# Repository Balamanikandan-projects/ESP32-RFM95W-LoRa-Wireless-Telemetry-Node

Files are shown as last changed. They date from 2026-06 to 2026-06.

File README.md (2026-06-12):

# Custom ESP32 & RFM95W LoRa Wireless Telemetry Node

[Full 3D board render]



A compact, high-performance, **4-layer custom PCB design** integrating an ESP32-WROOM-32E microcontroller with an RFM95W sub-GHz LoRa radio module. This hardware platform is engineered as a robust, low-power remote data acquisition node featuring an optimized power distribution network (PDN) and controlled-impedance RF path layout.

---

## 🚀 Key Features & Architectural Highlights

* **Core Processing:** Powered by an **ESP32-WROOM-32E**, managing application firmware, peripheral communication via SPI/UART, and deep-sleep low-power states.
* **Long-Range RF Connectivity:** Integrated **HOPERF RFM95W LoRa module** mapped over a high-speed synchronous SPI bus for long-range, sub-GHz wireless telemetry.
* **Advanced 4-Layer Stackup:** Engineered with a strict high-speed layout methodology:
  * **Layer 1 (Top):** Signal routing, RF traces, and critical high-frequency component placement.
  * **Layer 2 (Inner 1):** Solid **GND Plane** for low-impedance return paths and EMI shielding.
  * **Layer 3 (Inner 2):** Split **Power Plane** (+3.3V, VBAT, +5V) to ensure low-drop DC distribution.
  * **Layer 4 (Bottom):** Slow-moving control signals, programming buses, and local ground copper fill.
* **Dual-Input Automated Power Path:** Seamless automated power switching between USB Type-C ($5\text{V}$) and a Lithium-Polymer battery ($3.7\text{V} - 4.2\text{V}$) using a low-forward-drop Schottky barrier isolation diode.
* **Integrated Battery Management:** Onboard **TP4056 linear LiPo battery charger** with a programmable constant-current resistor network to regulate charging states safely.
* **High-Transient Power Regulation:** Equipped with a **TLV62569 synchronous buck regulator** providing a rock-solid $+3.3\text{V}$ rail capable of delivering up to $2\text{A}$ to handle active RF and Wi-Fi transmission bursts without voltage sags.

![PCB Layer Stackup Configuration]




---

## 🛠️ Hardware System Architecture & Floorplanning

The physical PCB layout is meticulously split into isolated functional blocks (Islands) to maximize signal integrity and prevent noise coupling:

### 1. Power Input & Charging (Zone 1)
* **USB-C Interface:** Standard 16-pin USB-C receptacle configured with dedicated $5.1\text{k}\Omega$ pull-down resistors on CC1/CC2 lines for downstream power negotiation.
* **Input Filtering:** High-frequency ceramic decoupling capacitors ($10\mu\text{F}$, 0603) placed immediately adjacent to the VBUS pins to suppress transient input ripples.

### 2. DC-DC High-Frequency Switching Regulator (Zone 2)
* **Switching Loop Minimization:** The $2.2\mu\text{H}$ power inductor ($L_1$) and input/output filters are placed directly next to the TLV62569 pads to minimize the high $di/dt$ switching loop area.
* **Isolated Feedback Network:** The voltage divider feedback resistors ($R_4, R_5$) are trace-isolated away from the noisy switching node to prevent output voltage fluctuations.

### 3. Microcontroller & Boot Strapping Constraints (Zone 3)
* **Deterministic Boot Logic:** Hardware pull-up and pull-down networks ($10\text{k}\Omega$) are hardwired on critical strapping pins (`GPIO 0`, `GPIO 5`, `GPIO 15`) to force stable system execution modes during reset and eliminate ambient floating noise.
* **Antenna Edge Clearance:** The ESP32's onboard trace antenna is positioned over a complete physical board overhang keepout zone, keeping all 4 copper layers fully clear of planes and traces to ensure 100% radiation efficiency.

### 4. RF Interface & Impedance Matching (Zone 4)
* **Bus Topography:** Parallel high-speed SPI bus routing (`MOSI`, `MISO`, `SCK`, `NSS`) designed with uniform lengths.
* **$50\Omega$ Antenna Path:** A straight-line **Pi-matching network** layout (Shunt C / Series R / Shunt C) routed into an edge-mounted coaxial SMA antenna jack, structured as a controlled $50\Omega$ microstrip transmission line.

### 5. UART Programming Breakout (Zone 5)
* Exposes standard `GND`, `TXD0`, `RXD0`, and `+3.3V` connections via a 4-pin male header for secure interface access using standard external USB-to-UART bridging modules.
![Complete KiCad Schematic Capture]





---

## 📊 Verification, Design Rules & Layout Integrity

* **Electrical Rules Check (ERC):** Achieved a clean **0 Errors / 0 Warnings** baseline in KiCad, eliminating overlapping net labels, unconfigured power pins, or short circuits.
* **Design Rules Check (DRC):** Clean zero-error verification. Surface-mount pad routing challenges (such as USB-C tight mechanical clearances) were bypassed using direct-to-plane localized micro-vias down to the Inner Layer 2 Ground plane, reducing track parasitics and eliminating top-layer signal crowding.
![DRC Clean Pass Window]


---

## 💻 Technical Toolstack
* **EDA Suite:** KiCad (Schematic Capture, Custom Footprint Management, 4-Layer PCB Layout)
* **Component Form Factor:** Optimized using a space-saving $0603$ SMD footprint strategy for passives to secure layout compactness while maintaining manual bench-test and debugging solderability.

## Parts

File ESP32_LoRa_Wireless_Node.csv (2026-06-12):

Id | Designator | Footprint | Quantity | Designation | Supplier and ref
1 | J1 | USB_C_Receptacle_GCT_USB4085 | 1 | USB_C_Receptacle_USB2.0_16P
2 | C10,C11,C9,C7,C8 | C_0603_1608Metric | 5 | 100nF
3 | U2 | HOPERF_RFM9XW_SMD | 1 | RFM95W-868S2
4 | C6,C2,C5,C4,C3,C1 | C_0603_1608Metric | 6 | 10uF
5 | BAT_CONN1 | JST_PH_B2B-PH-K_1x02_P2.00mm_Vertical | 1 | Conn_01x02_Pin
6 | D1 | D_SOD-123 | 1 | D_Schottky
7 | R1,R2 | R_0603_1608Metric | 2 | 5.1k
8 | R10,R9,R6,R8,R7 | R_0603_1608Metric | 5 | 10k
9 | U1 | ESP32-WROOM-32D | 1 | ESP32-WROOM-32E
10 | U4 | SOT-563 | 1 | TLV62569ADRL
11 | U3 | SOIC-8-1EP_3.9x4.9mm_P1.27mm_EP2.41x3.3mm_ThermalVias | 1 | TP4056-42-ESOP8
12 | R5 | R_0603_1608Metric | 1 | 90.9k
13 | R4 | R_0603_1608Metric | 1 | 402k
14 | R3 | R_0603_1608Metric | 1 | 1.2k
15 | L1 | L_0805_2012Metric | 1 | 2.2uH
16 | J3 | PinHeader_1x04_P2.54mm_Vertical | 1 | Conn_01x04_Pin
17 | J2 | SMA_Amphenol_132134_Vertical | 1 | Conn_Coaxial

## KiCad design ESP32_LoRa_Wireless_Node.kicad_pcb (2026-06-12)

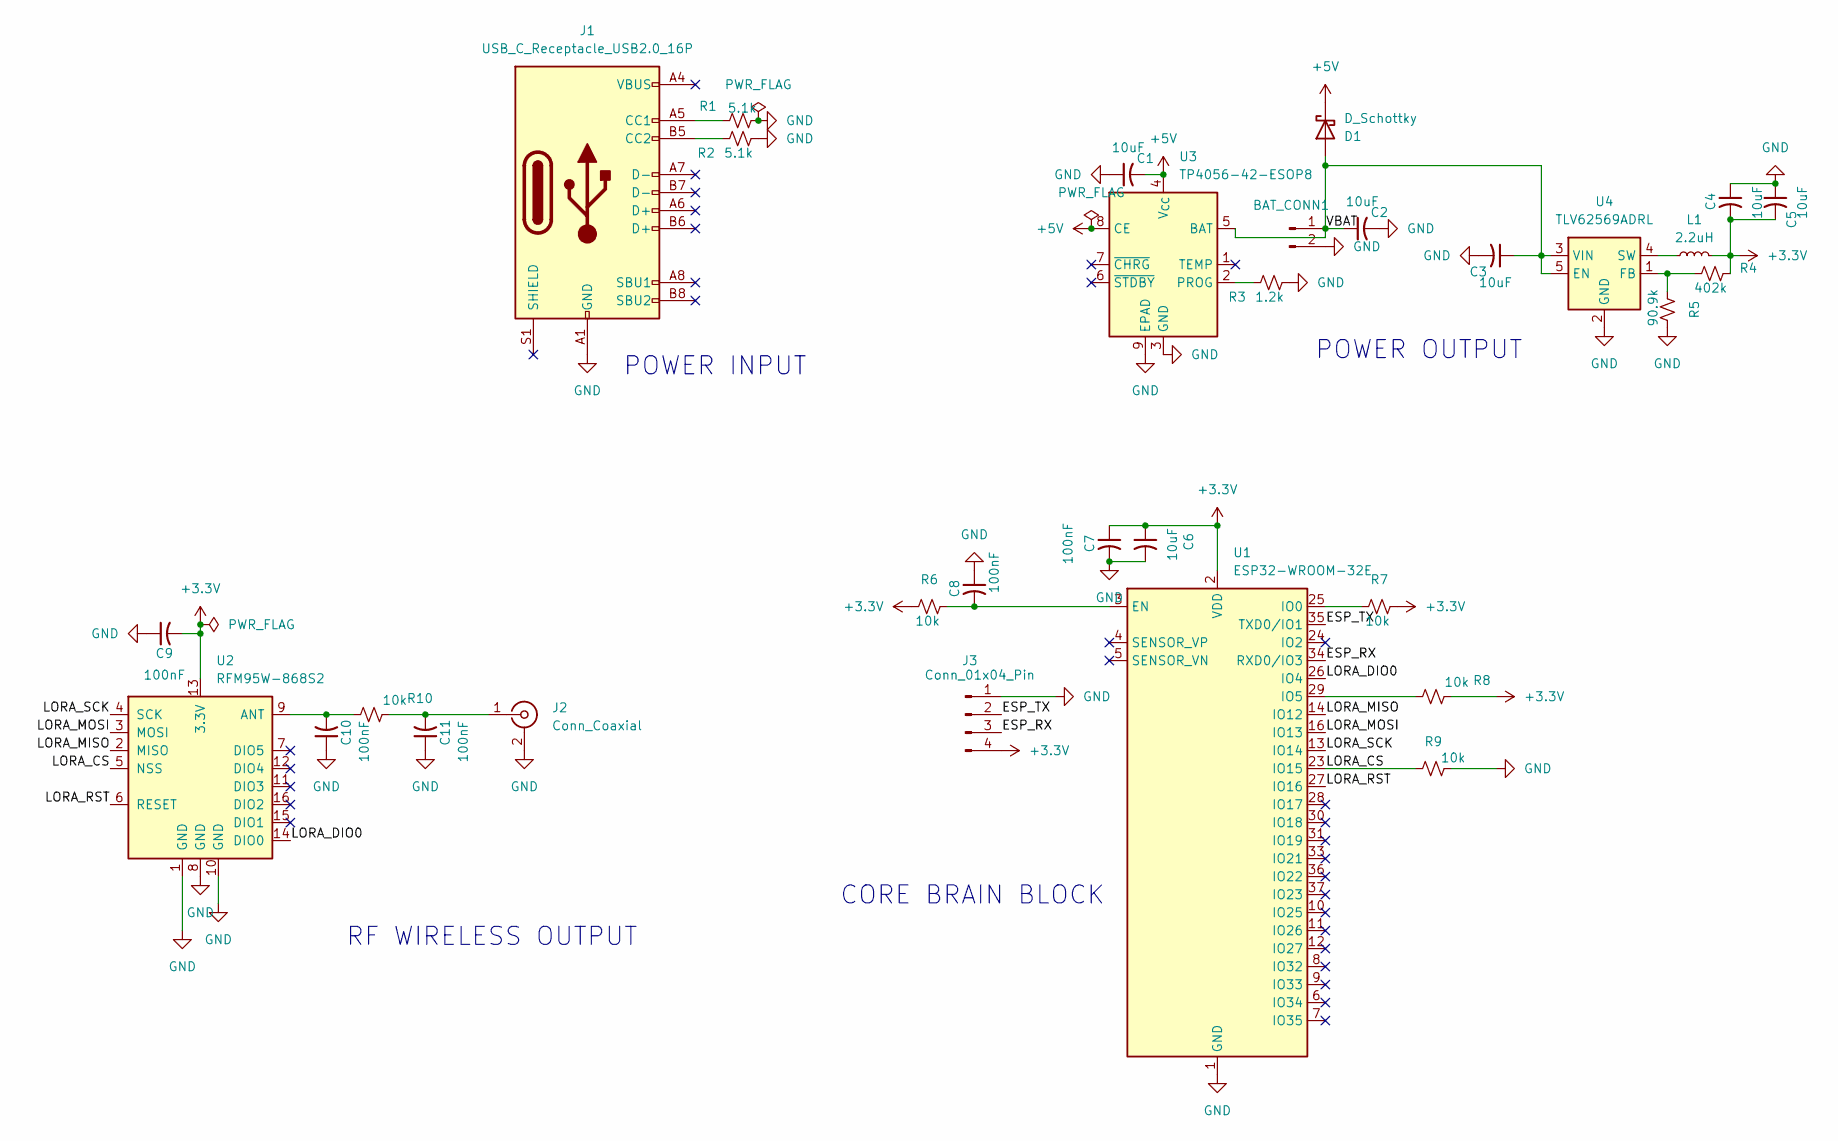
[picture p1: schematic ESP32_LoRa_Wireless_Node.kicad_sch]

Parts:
BAT_CONN1: Conn_01x02_Pin; JST_PH_B2B-PH-K_1x02_P2.00mm_Vertical
C1, C2, C3, C4, C5, C6: 10uF; C_0603_1608Metric
C7, C8, C9, C10, C11: 100nF; C_0603_1608Metric
D1: D_Schottky; D_SOD-123
J1: USB_C_Receptacle_USB2.0_16P; USB_C_Receptacle_GCT_USB4085
J2: Conn_Coaxial; SMA_Amphenol_132134_Vertical
J3: Conn_01x04_Pin; PinHeader_1x04_P2.54mm_Vertical
L1: 2.2uH; L_0805_2012Metric
R1, R2: 5.1k; R_0603_1608Metric
R3: 1.2k; R_0603_1608Metric
R4: 402k; R_0603_1608Metric
R5: 90.9k; R_0603_1608Metric
R6, R7, R8, R9, R10: 10k; R_0603_1608Metric
U1: ESP32-WROOM-32E; ESP32-WROOM-32D
U2: RFM95W-868S2; HOPERF_RFM9XW_SMD
U3: TP4056-42-ESOP8; SOIC-8-1EP_3.9x4.9mm_P1.27mm_EP2.41x3.3mm_ThermalVias
U4: TLV62569ADRL; SOT-563

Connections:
+3.3V: C4.2, C5.2, C6.1, C7.1, C9.2, J3.4, L1.2, R4.2, R6.1, R7.2, R8.2, U1.2 (VDD), U2.13 (3.3V)
+5V: C1.2, D1.1 (K), U3.4 (V_{CC}), U3.8 (CE)
/ESP_RX: J3.3, U1.34 (RXD0/IO3)
/ESP_TX: J3.2, U1.35 (TXD0/IO1)
/LORA_CS: R9.1, U1.23 (IO15), U2.5 (NSS)
/LORA_DIO0: U1.26 (IO4), U2.14 (DIO0)
/LORA_MISO: U1.14 (IO12), U2.2 (MISO)
/LORA_MOSI: U1.16 (IO13), U2.3 (MOSI)
/LORA_RST: U1.27 (IO16), U2.6 (RESET)
/LORA_SCK: U1.13 (IO14), U2.4 (SCK)
/VBAT: BAT_CONN1.1, C2.1, C3.1, D1.2 (A), U3.5 (BAT), U4.3 (VIN), U4.5 (EN)
GND: BAT_CONN1.2, C1.1, C2.2, C3.2, C4.1, C5.1, C6.2, C7.2, C8.1, C9.1, C10.1, C11.1, J1.A1 (GND), J1.A12 (GND), J1.B1 (GND), J1.B12 (GND), J2.2 (Ext), J3.1, R1.2, R2.2, R3.2, R5.2, R9.2, U1.1 (GND), U1.15 (GND), U1.38 (GND), U1.39 (GND), U2.1 (GND), U2.8 (GND), U2.10 (GND), U3.3 (GND), U3.9 (EPAD), U4.2 (GND)
unnamed: J1.A5 (CC1), R1.1
unnamed: J1.B5 (CC2), R2.1
unnamed: C11.2, J2.1 (In), R10.2
unnamed: C8.2, R6.2, U1.3 (EN)
unnamed: R7.1, U1.25 (IO0)
unnamed: R8.1, U1.29 (IO5)
unnamed: C10.2, R10.1, U2.9 (ANT)
unnamed: R3.1, U3.2 (PROG)
unnamed: R4.1, R5.1, U4.1 (FB)
unnamed: L1.1, U4.4 (SW)

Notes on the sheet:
POWER INPUT
CORE BRAIN BLOCK
POWER OUTPUT
RF WIRELESS OUTPUT

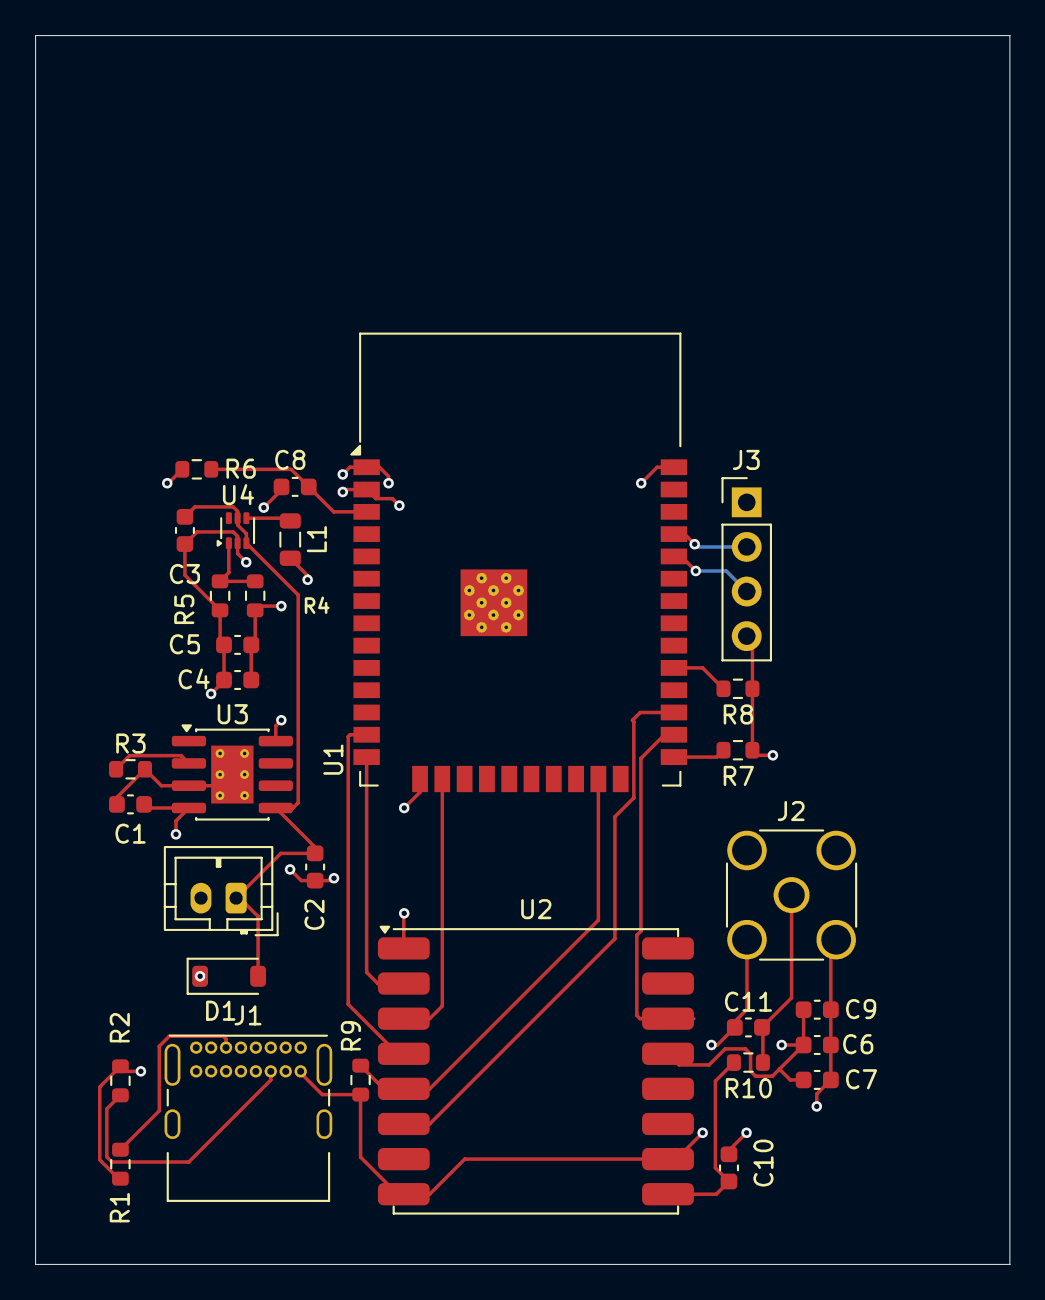
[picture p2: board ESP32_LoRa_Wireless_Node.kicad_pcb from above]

Board: 4 copper layers, 55.5 x 70.0 mm, 31 parts (0 on the bottom side), 22 nets.
